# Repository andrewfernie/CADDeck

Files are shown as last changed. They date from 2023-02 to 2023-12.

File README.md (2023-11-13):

# CADDeck
This is the source repository for the software for CADDeck, a combined joystick and touch panel display suitable for use with common CAD programs. 
## Hardware Configuration
### Current "AFUDirk" hardware
It is configured to use the hardware designed by AFUDirk here (https://github.com/AFUDIrk/CADDeck)
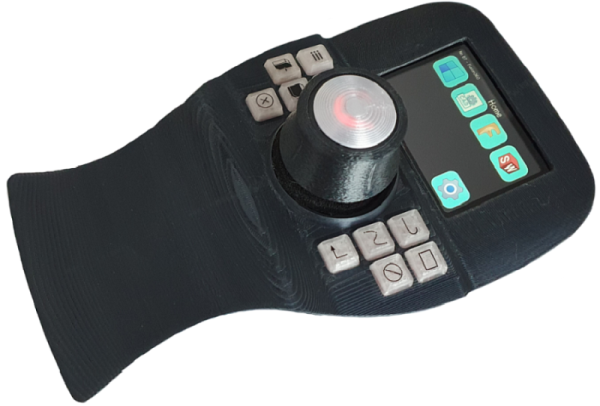
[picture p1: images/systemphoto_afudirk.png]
AFUDirk System Photo

It includes:
1. Two axis joystick (e.g. for X, Y pan)
2. Two axis knob (up/down and rotate left/right) with a capacitive switch for mode select 
3. Ten switches around the base (e.g. measure, ESC...)
5. LCD touch panel with up to 10 screens of 12 buttons

All H/W buttons as well as the touch panel buttons are programmable through a web page.

Basic principles of operation and software build still apply, and are described below, but details may differ so some updates to the text are needed.

### Version 1 (deprecated)
Initial versions of the software were built for this hardware that has a knob with four buttons and a thumbwheel encoder. No work is currently being done on this version of the hardware, but details can be found in the branch Version_1-Four_Buttons.
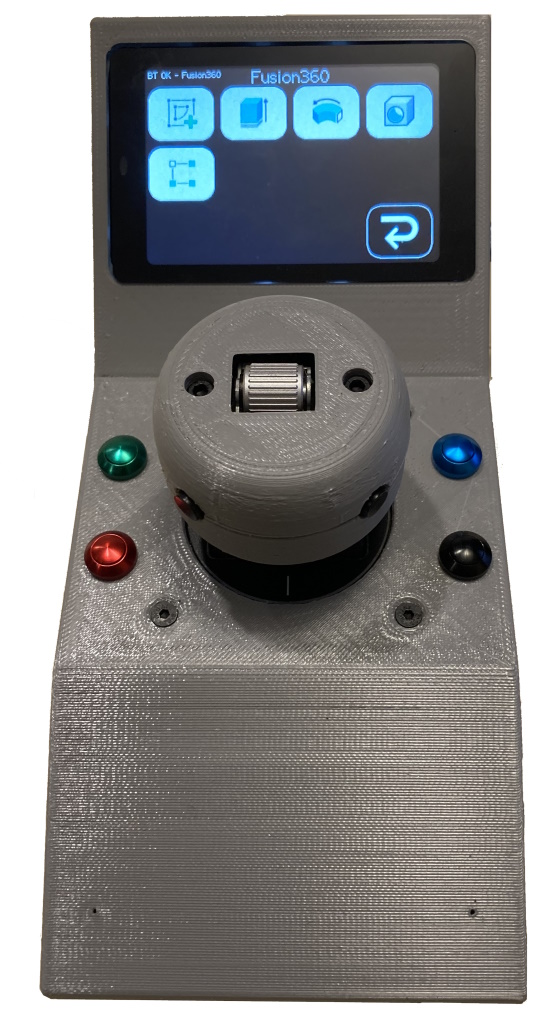
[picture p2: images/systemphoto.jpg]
Original Version 1 System


## PC Interface
It connects to the PC via Bluetooth using the HID interface (i.e. it looks like a keyboard and mouse to the PC). A USB-C port is provided for power and to download code. Location of the USB-C port on the left side is not ideal, but that is where it is on the screen being used. It should be possble to run power to the unit and hardwire it to the screen rather than using the USB-C for power but I have not tried this.

## SpaceMouse Emulation
While the basic mode uses mouse/keyboard combinations for viewpoint control, a SpaceMouse emulation mode is also available. This requires an external Raspberry Pi Pico board running this software (https://github.com/andrewfernie/magellan-spacemouse), as a fork from the project of the same name by "jfedor2". This board is connected to a serial port on the CADDeck WT32-SC01 board, and is also connected to the PC via USB. Further work is required to avoid the need for simultaneous use of Bluetooth and USB interfaces.

## Touch Panel
The touch panel is adapted from Dustin Watt's FreeTouchDeck project (https://github.com/DustinWatts/FreeTouchDeck.git) which I modified to increase the button count, etc.  (https://github.com/andrewfernie/FreeTouchDeckWT32.git). For this project I added support for the joystick, encoder, and buttons.  The easiest way to get it going is to use a WT32-SC01 board (http://www.wireless-tag.com/portfolio/wt32-sc01/). Purchase the basic board, not the "Plus" version as the Plus uses a parallel interface to the LCD panel and doesn't leave enough IO lines free for the joystick and buttons, etc. The board includes an ESP32 module, and a 3.5" LCD with capacitive touchscreen.

## S/W Build Notes:
1. The build uses the PlatformIO IDE for VSCode. Install VSCode, then the PlatformIO plugin and you should be good to go.  
2. You need to make sure that the appropriate pins are defined for your hardware configuration. I built mine for the WT32-SC01 and have built the code for a handwired ESP32 module + resistive touchscreen. 
3. You may see build messages like
        
        In file included from include/CADDeck.h:14,
                 from include/SaveConfig.h:3,
                 from src/SaveConfig.cpp:1:
        .pio/libdeps/esp-wrover-kit/TFT_eSPI/TFT_eSPI.h:909:8: warning: #warning >>>>------>> TOUCH_CS pin not defined, TFT_eSPI touch functions will not be available! [-Wcpp]
        #warning >>>>------>> TOUCH_CS pin not defined, TFT_eSPI touch functions will not be available!`
    
    You can get rid of these by defining TOUCH_CS in platformio.ini to any unused pin that is a valid output pin. The alternative is to not define TOUCH_CS (delete the line, or put a semi-colon in front of it) and just ignore the messages.

        #define TOUCH_CS=33

4. The system tries to display the logo in "CADDeck_logo.bmp" at startup. If you don't want anything displayed make sure that the file doesn't exist. In this case you will see a message like the following on the serial port. As long as you didn't weant anything displayed at startup ignore the message.
        
        [  1159][E][vfs_api.cpp:104] open(): /littlefs/logos/CADDeck_logo.bmp does not exist, no permits for creation

5. You may  see some error messages like 
   
        [vfs_api.cpp:104] open(): /littlefs/list does not exist 
        
   This is a known issue with ESPAsyncWebsServer related to LittleFS supporting folders while SPIFFS does not. See https://github.com/lorol/

6. Having trouble? There are some debug messages that can be enabled in FreeTouchDeck.h
   
        #define LOG_MSG_BASIC 1
        #define LOG_MSG_LEVEL 1  // 1=ERROR, 2=ERROR+WARN, 3=ERROR+WARN+INFO
        #define LOG_MSG_DEBUG 0
        #define LOG_MSG_TOUCH_DEBUG 0  // messages to console each time a touch is detected

   Try setting LOG_MSG_LEVEL to 3 and you will get quite a few more status messages

# Setup
Once the unit is assembled and the display is coming up you should see the main page.
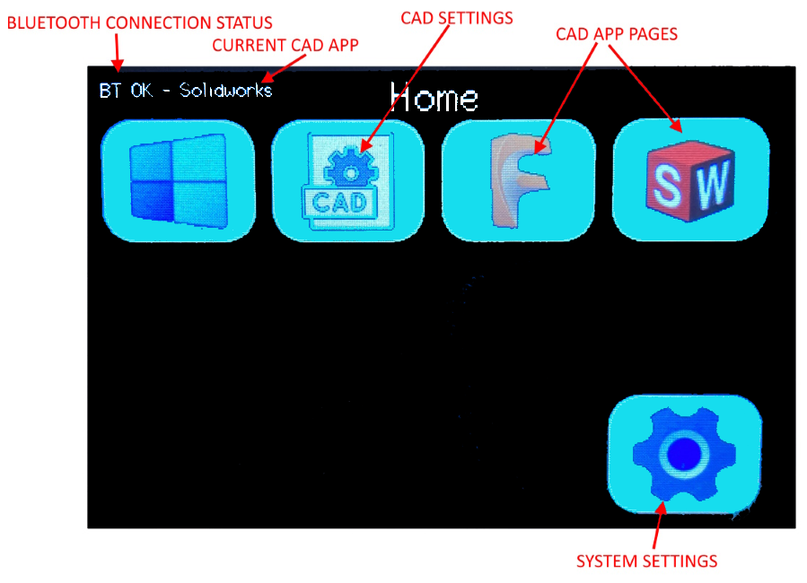
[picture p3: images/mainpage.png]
Main Page


Go to the CAD Settings page.
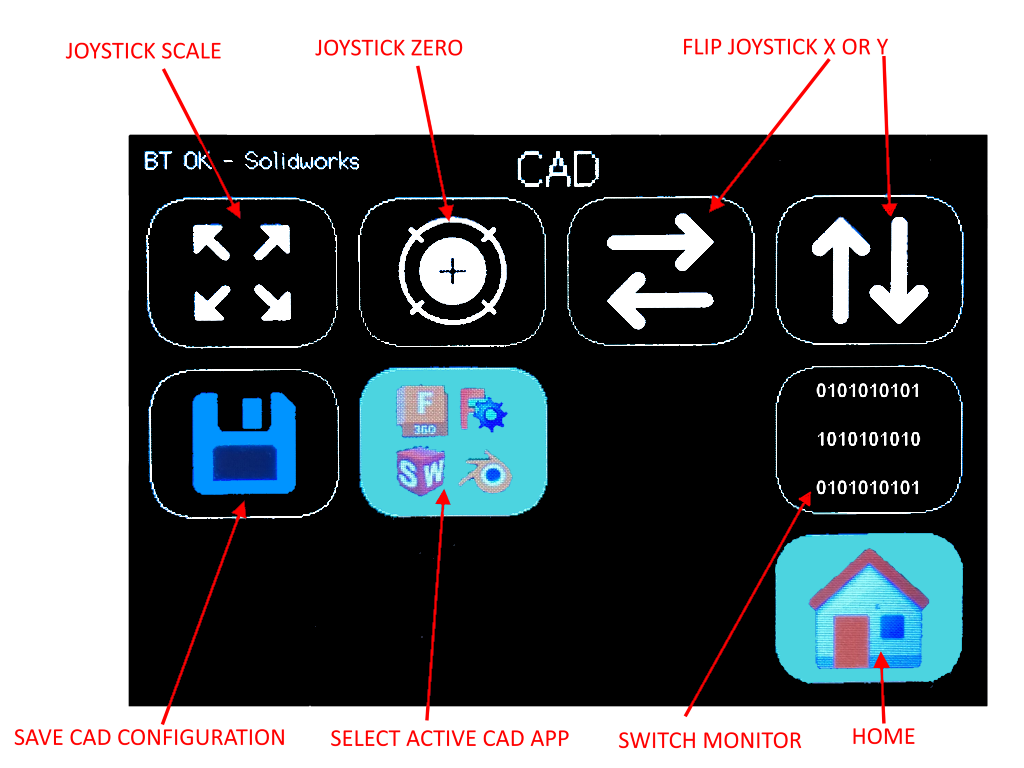
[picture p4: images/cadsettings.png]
CAD Settings Page


Then the Switch Monitor page.

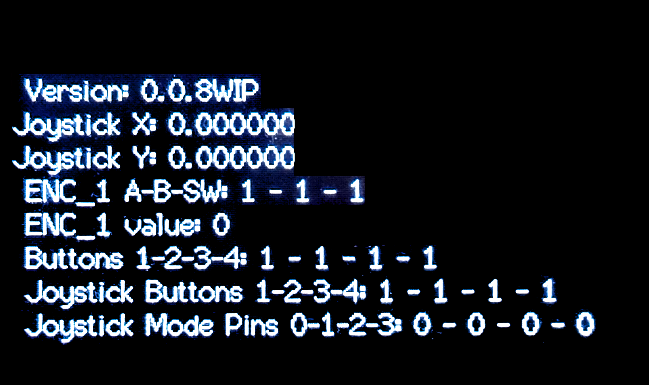
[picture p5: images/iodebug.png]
Switch Monitor Page


It displays the status of the joystick, encoder, and buttons. You should be able to see the result of each joystick movement or button selection. Note that the values are shown as 1 when not selected and 0 when selected (pushed).

The joystick X and Y data may be bouncing around a bit. This is normal as the joystick is not calibrated at this point. To calibrate the joystick:
1. Go back to the CAD Settings page
2. Press the Joystick Zero button when the joystick is centered and still. This sets the zero point for the joystick. 
3. Press the Joystick Scale button and move the joystick around to the extremes in X and Y. You have 5s. Once the function finishes the calibration parameters will be calculated and the joystick should show a range of roughly +/- 1 in both X and Y. 
4. If you are happy with the calibration, press the Save CAD Configuration button and the parameters will be saved to the cadparams.json file in the ESP32. This file can be downloaded from the ESP32 to your PC via the CAD Settings page in the configurator. It is a good idea to do this and to copy the file to the data\config folder in the CADDeck code so that you won't lose the parameters next time you upload the data folder to the ESP32.
4.  If you are not happy with the results, try again.

Bind your computer to the CADDeck using the Bluetooth setings page on your computer.

# Configuration
Note that all of the pages shown or mentioned above are samples. Every page can be reorganized and customized to suit your needs via the configurator.

## WiFi Configuration
The configurator is accessed via a web browser on a computer or tablet connected to the same network as the ESP32. To enable the configurator go to the settings page on the touch panel and select the WiFi Enable button.  
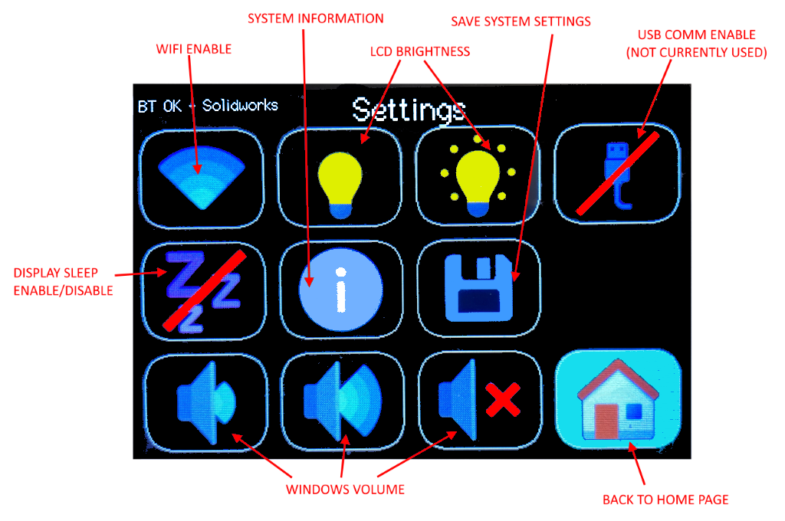
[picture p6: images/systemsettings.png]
System Settings


If you have already configured your wifi connection in wificonfig.json you should see a message saying that it has connected to the wifi and will display the IP address. At that point you can go to your browser and enter the IP address top connect. The configurator will be displayed.
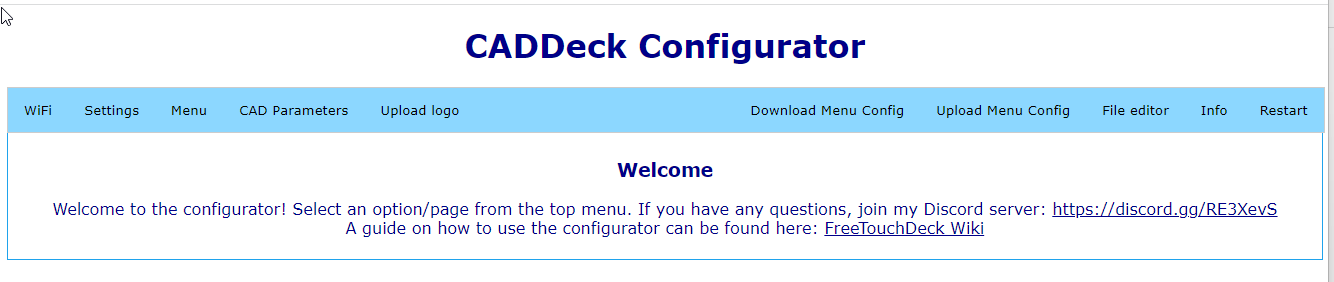
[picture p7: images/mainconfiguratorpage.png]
Configurator Main Page


If you have not already configured the wifi you should see a message saying that an access point (AP) has been created with a network name and IP address. You will need to connect your computer to the network provided, and then point your browser at the IP address. Once the configurator screen is displayed in your browser go to the wifi page and enter your network SSID and password. Then select "Save WiFi Config" to save the settings. 

## Menu Configuration
The main change from the original FreeTouchDeck is to allow more buttons per page  - the screen area is just a bit smaller than the size of twelve StreamDeck buttons which seems reasonable. The code is currently set to three rows of four buttons, but can be changed to three rows of five buttons (or two rows of four, etc.) by modifying CADDeck.h: "#define BUTTON_ROWS 3" and "#define BUTTON_COLS 5".  In principle it should support larger arrays, but not tested, and the configurator page is set to a maximum of 3x5. 

The configurator displays an array of three rows of five buttons, with a drop down list to select the menu page to be modified. If you are using fewer than 3x5, simply ignore the extra rows and columns. On the to-do list is to generate the HTML dynamically to correspond with the number of rows and columns.
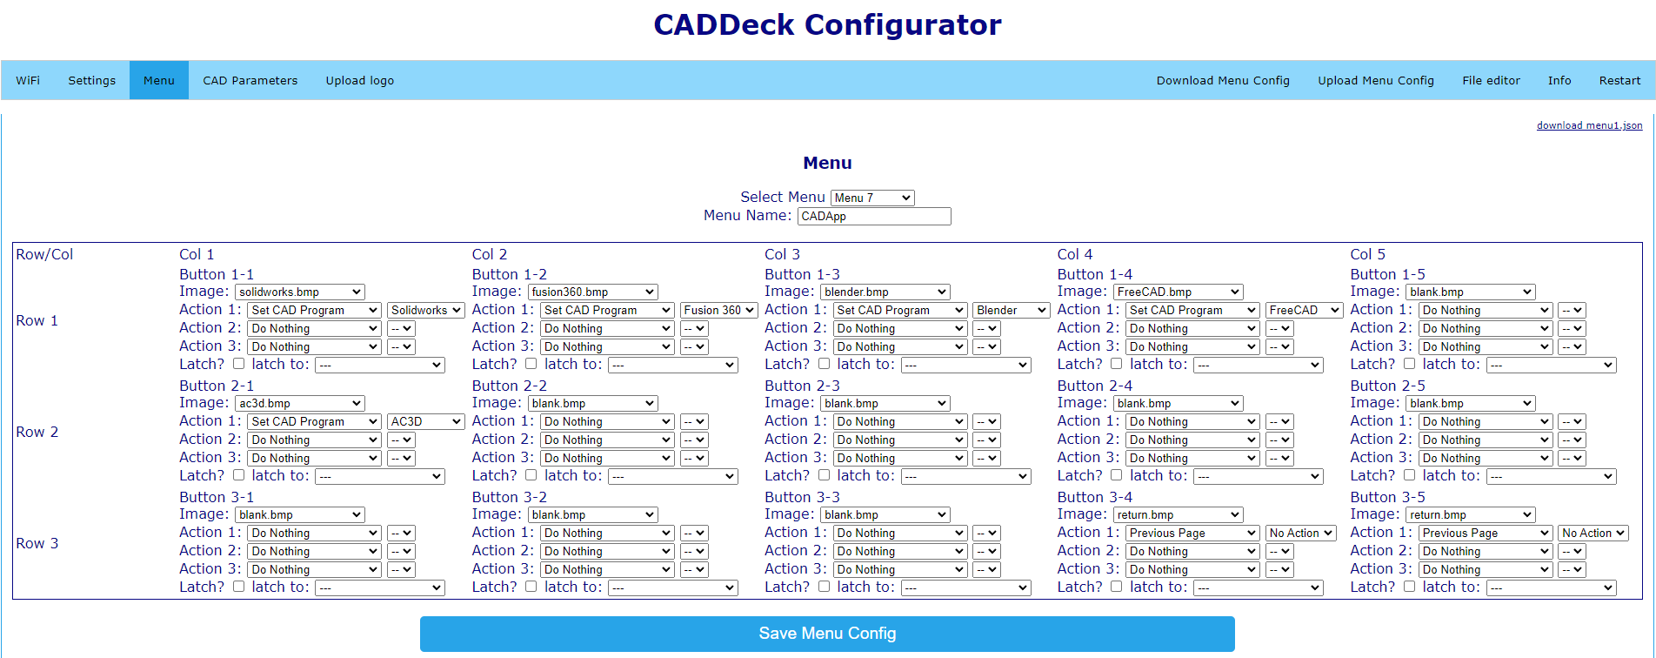
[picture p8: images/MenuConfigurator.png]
Menu Configurator


Each Menu page has a 2D array of programmable buttons, and each button has an array of 3 actions that can be defined for when the button is pressed.

You can set different background colors for a button that performs an action (black background in the image above), or links to another menu (light blue in the image.) This is controlled on the Settings page of the configurator.

If you don't want to use all buttons use the configurator to set the logo to "blank.bmp" and make sure that there are no actions defined for that button. Any button with those characteristics will not be drawn.

One limitation is the size of the FLASH used for the configuration files and icons displayed on the touch screen. The icons are 75x75 24-bit color BMP files, each one taking about 17kB.  If you run out of space your only option is to check to see if any are unused and delete them.

## Hardware Buttons
Configuration of the hardware buttons is via a dedicated page within the same web-based configurator as for the LCD panel. 
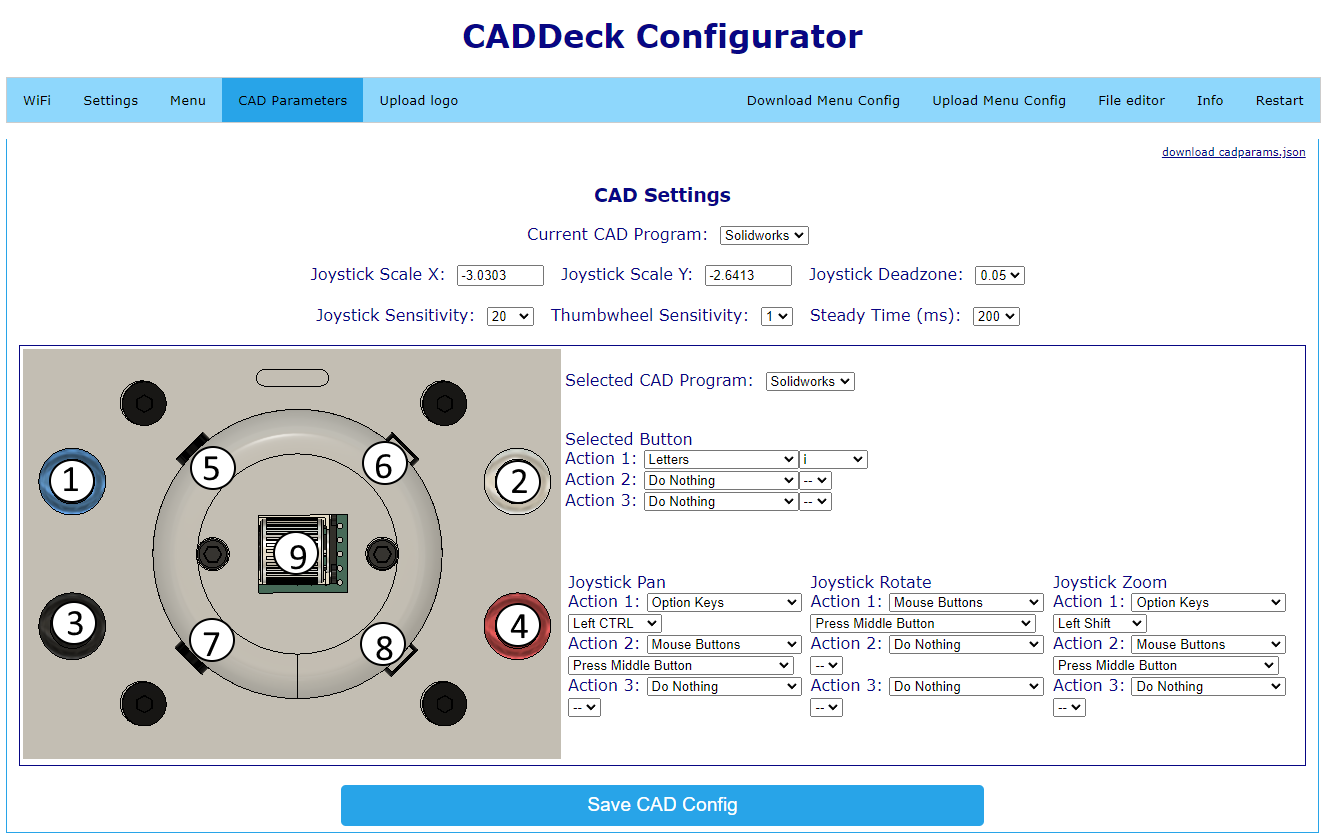
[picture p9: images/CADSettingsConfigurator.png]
CAD Settings Configurator


The top section includes:
1. Current CAD program: This is the program whose settings will be loaded when the CADDeck is restarted
2. X and Y scaling parameters for the joystick. These can be set manually, but a function is provided to capture data as the joystick is moved to its extremes and calculate the scalings for you. The output scaling is +/-1
3. Joystick deadzone. Any X or Y value with an absolute value below this number is set to zero.
4. Joystick sensitivity. Joystick values are multiplied by this as they are converted to mouse movement commands
5. Thumbwheel sensitivity. The encoder value is multiplied by this as it is converted to mouse movement commands

Below that is the button action definition. The same approach to defining the actions is used as for the LCD panel buttons. The actions are:
1. Selected CAD program. The program whose settings are being modifed in that part of the configurator. Separate definitions of these settings are kept for each of the five CAD programs available.
2. Selected Button. One of the nine buttons shown in the image to the left. Click  one of the indicated areas in the image then modify the actions for that button as needed.
3. The actions that must be taken to enable pan/rotate/zoom to be controlled by the joystick (i.e. the mouse) within the selected CAD program. Note that the definition of what is needed to control pan/rotate/zoom is separate from which button enables that mode. As an example, Solidworks needs the middle mouse button to be held down to rotate the view. So, JoystickRotate/Action1 is set to "Mouse Buttons" and Value1 is set to "Press Middle Button". To assign the Rotate function to button 8, click "8" in the image to the left, then set SelectedButton/Action1 to "CAD Functions" and Value1 to "Joystick Rotate"
Configuring the Rotate function
At the very bottom is the "Save CAD Config" button. When selected the settings for all CAD programs are saved on the ESP32 in file cadparams.json

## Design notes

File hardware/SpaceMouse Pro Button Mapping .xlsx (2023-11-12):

Button Mapping
CAD Deck Button | Button Bit Sent To 3DConnexion driver | SpaceMouse Pro Button
0 | 12
1 | 13 | 1
2 | 14 | 2
3 | 15 | 3
4 | 22 | 4
5 | 25 | ESC
6 | 23 | CTRL
7 | 24 | ALT
8 | 0 | SHIFT
9 | 1 | MENU
10 | 2 | FIT
11 | 4 | T
12 | 5 | R
13 | 8 | F
14 | 26 | Square with Arrow (Rotate View)
15 | 3 | Lock
16 | 6 | Not available
17 | 7 | Not available
18 | 9 | Not available

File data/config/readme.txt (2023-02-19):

Before downloading the file system to the board rename the file:
	wificonfig.json.default
	
to
	wificonfig.json

and edit the ssid and password fields to your wifi network name and password.

You can always set these through the configurator when the wifi is running as an AP, 
but then you will have to repeat that process every time you download the file system again.

wificonfig.json is listed in the .gitignore file so that it doesn't get uploaded to a public 
repository by mistake and expose your wifi credentials.

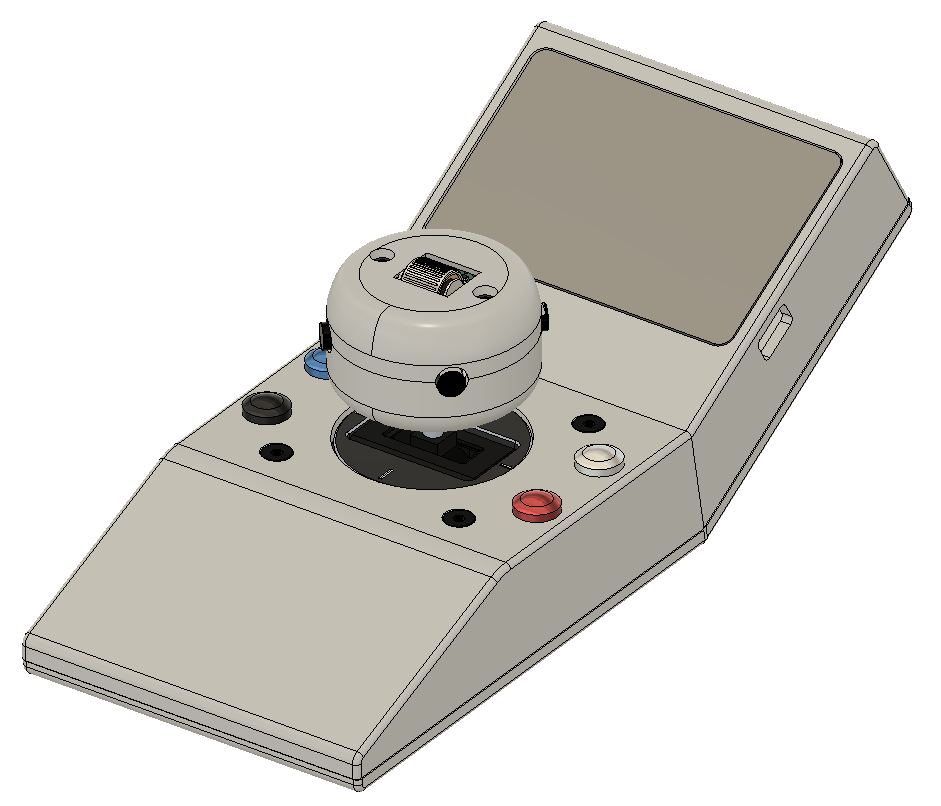
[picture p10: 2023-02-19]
hardware/ExteriorView1.png

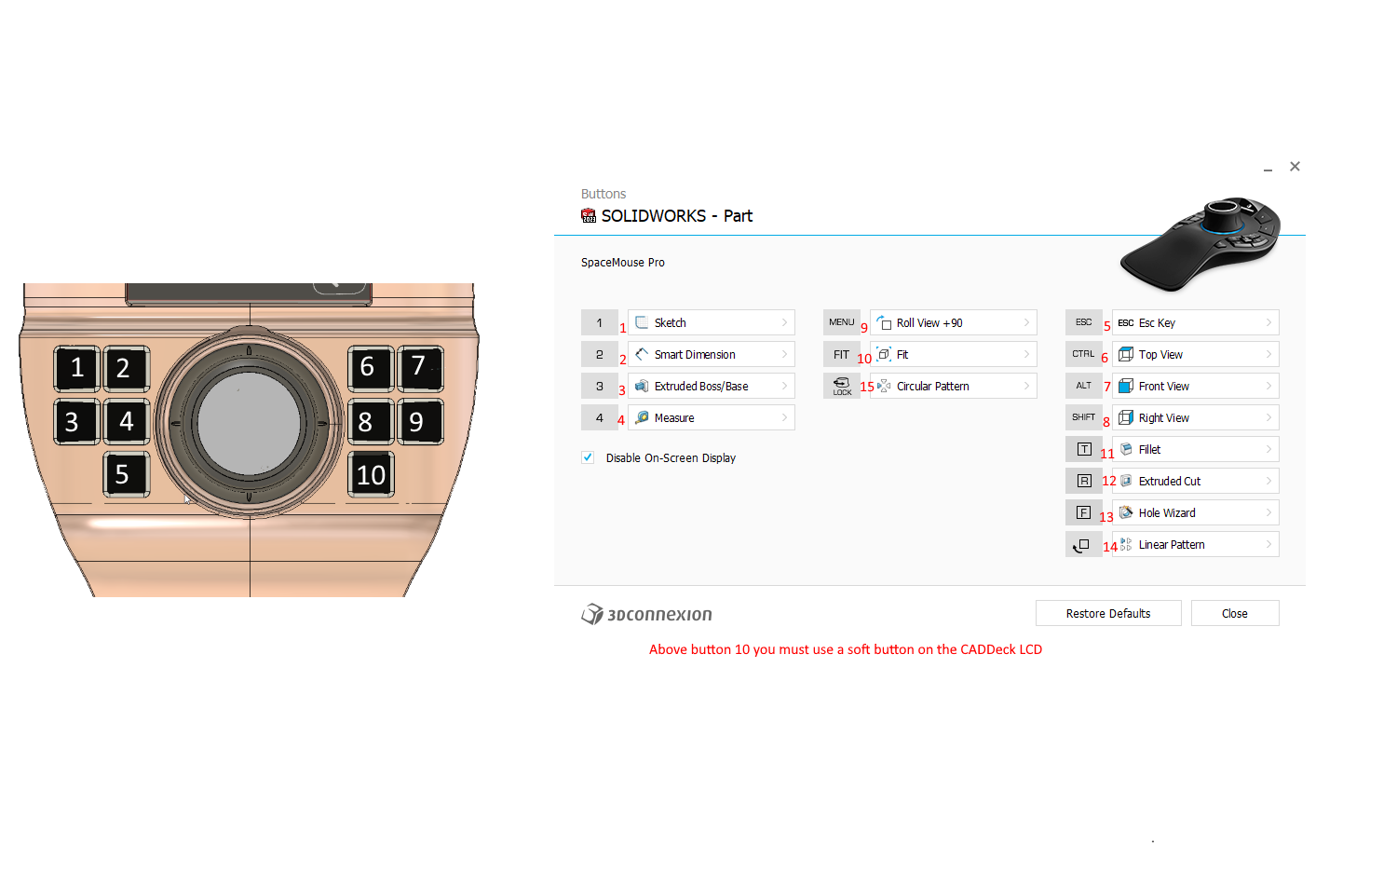
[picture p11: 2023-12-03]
images/SpaceMouseButtonMapping.png

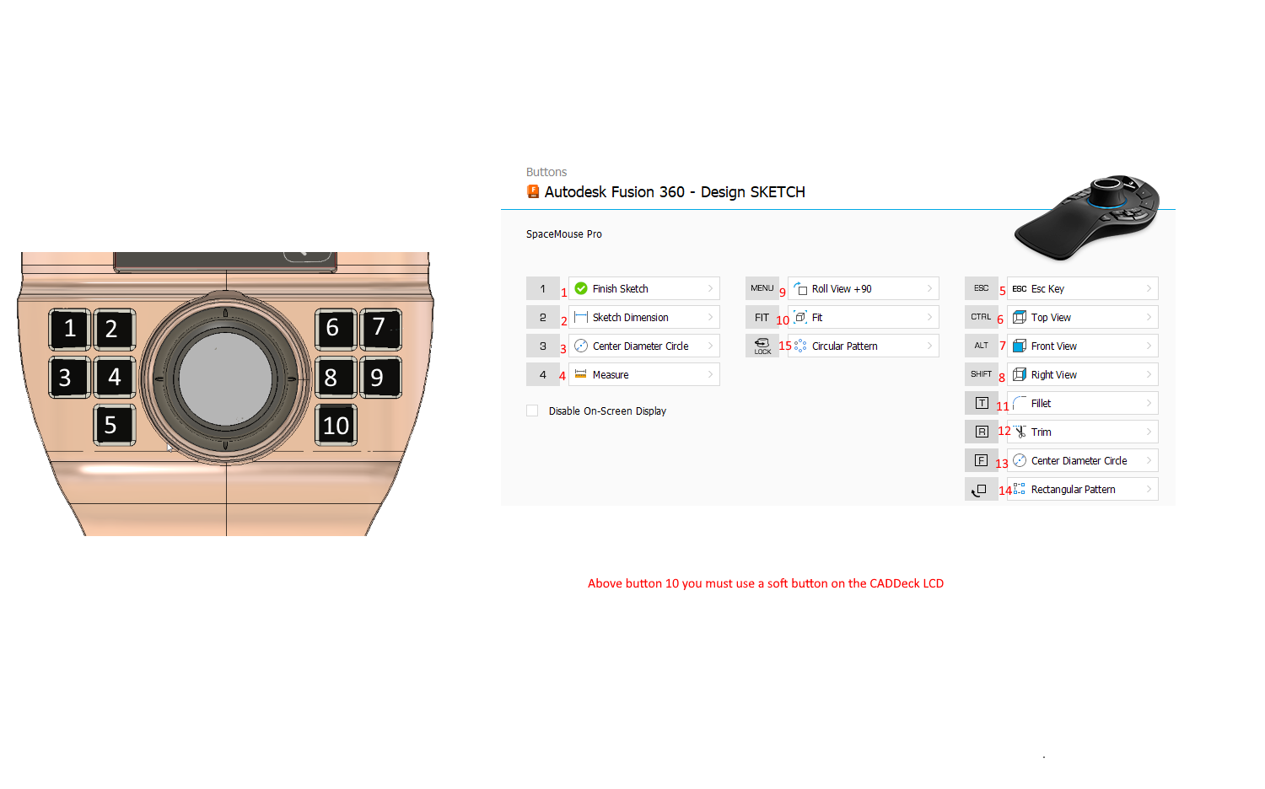
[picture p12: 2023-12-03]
images/SpaceMouseButtonMapping-F360Sketch.png

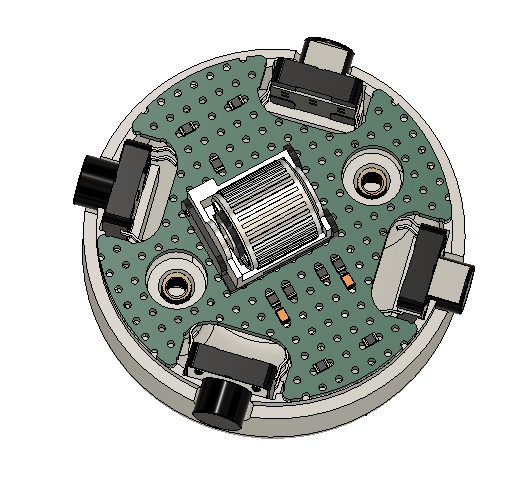
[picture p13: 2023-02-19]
images/KnobInterior.png

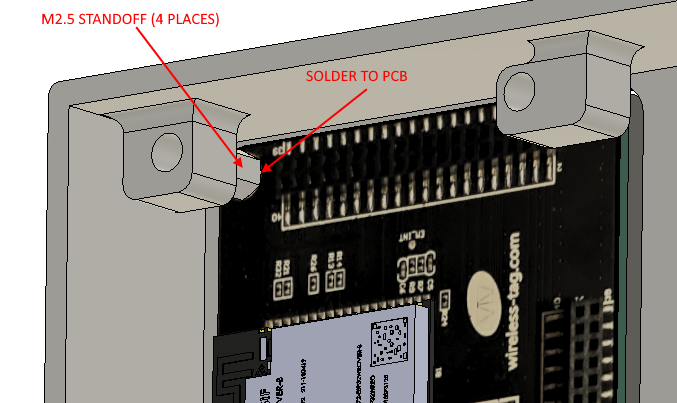
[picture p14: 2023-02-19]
images/ScreenAttachment.png

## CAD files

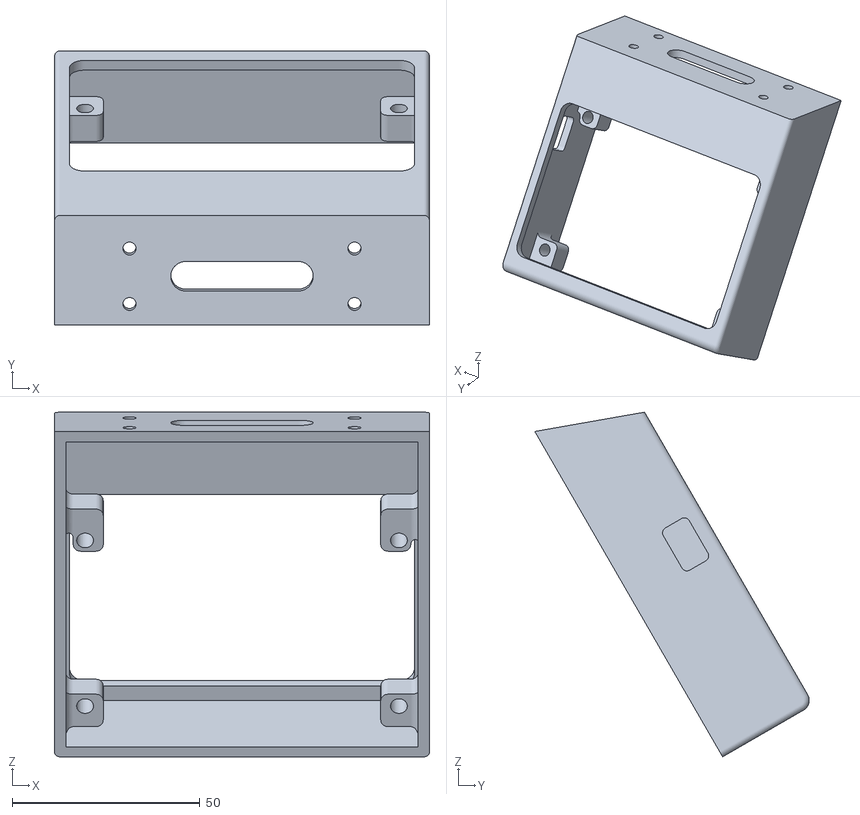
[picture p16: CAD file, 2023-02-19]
hardware/Case/Case Top Rear.stl
100.0 x 73.2 x 91.9

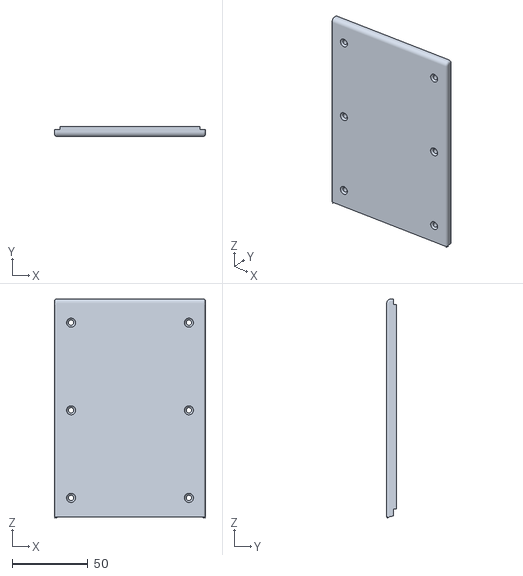
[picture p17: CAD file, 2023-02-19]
hardware/Case/Case Bottom Front.stl
100.0 x 6.50 x 145.0

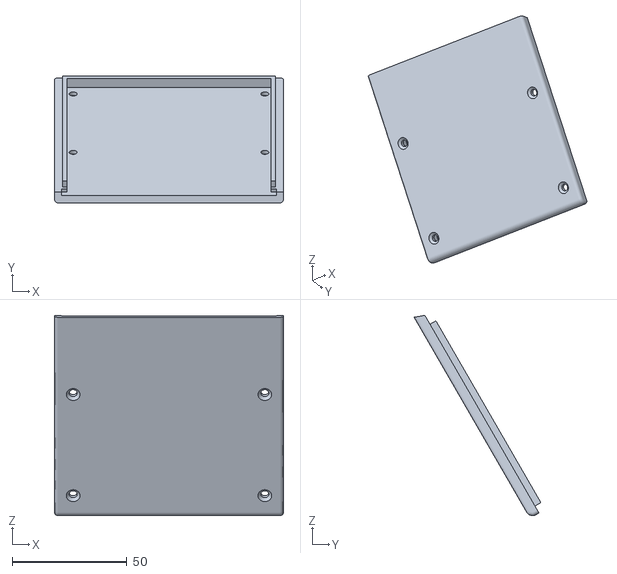
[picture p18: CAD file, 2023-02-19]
hardware/Case/Case Bottom Rear.stl
100.0 x 55.4 x 87.5

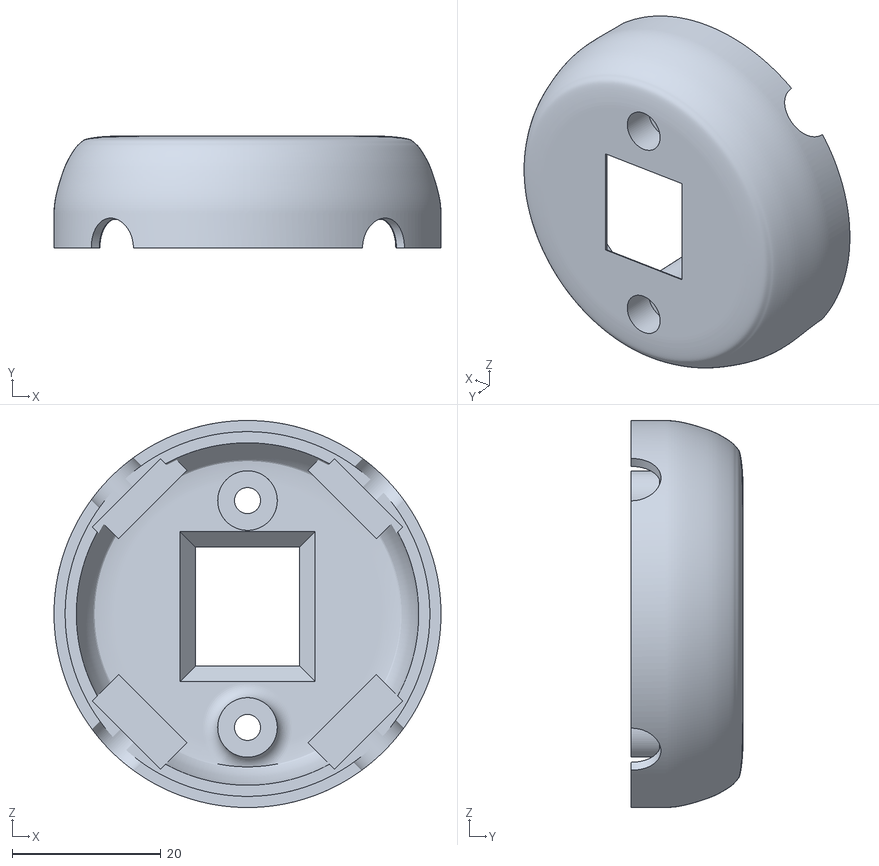
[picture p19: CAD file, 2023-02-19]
hardware/Case/Knob Top.stl
52.0 x 15.0 x 52.0

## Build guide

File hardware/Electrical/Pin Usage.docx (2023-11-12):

Pin Usage

December 10, 2022

11:00 AM

GPIO | Input | Output | Function | ADC | DAC | RTC | Capacitive Touch | WT32-SC01 | CADDeck Std | CADDeck 10 Buttons | Notes
0 | pulled up | OK | | ADC2_CH1 | | RTC_GPI011 | T1 | I2S_MCLK (Available) | | | outputs PWM signal at boot, must be LOW to enter flashing mode
1 | TX pin | OK | | | | | | | | | debug output at boot
2 | OK | OK | | ADC2_CH2 | | RTC_GPI012 | T2 | Available | | | connected to on-board LED, must be left floating or LOW to enter flashing mode
3 | OK | RX pin | | | | | | | | | HIGH at boot
4 | OK | OK | | ADC2_CH0 | | RTC_GPI010 | T0
5 | OK | OK | | | | | | I2S_SCLK (Available) | | | outputs PWM signal at boot, strapping pin. I2S is a digital audio interface.
6 | x | x | (SCK/CLK) | | | | | | | | connected to the integrated SPI flash
7 | x | x | (SDO/SD0) | | | | | | | | connected to the integrated SPI flash
8 | x | x | (SDI/SD1) | | | | | | | | connected to the integrated SPI flash
9 | x | x | (SHD/SD2) | | | | | | | | connected to the integrated SPI flash
10 | x | x | (SWP/SD3) | | | | | | | | connected to the integrated SPI flash
11 | x | x | (CSC/CMD) | | | | | | | | connected to the integrated SPI flash
12 | OK | OK | | ADC2_CH5 | | RTC_GPI015 | T5 | (TFT_MISO) | | | boot fails if pulled high, strapping pin
13 | OK | OK | | ADC2_CH4 | | RTC_GPI014 | T4 | LCD_SDA (TFT_MOSI)
14 | OK | OK | | ADC2_CH6 | | RTC_GPI016 | T6 | Output LCD_SCL (TFT_SCLK) | | | outputs PWM signal at boot
15 | OK | OK | | ADC2_CH3 | | RTC_GPI013 | T3 | TFT_CS | | | outputs PWM signal at boot, strapping pin
16 | OK | OK | | | | | | Not available on WROVER-B
17 | OK | OK | | | | | | Not available on WROVER-B
18 | OK | OK | | | | | | I2C_SDA (TP,EM20918) | Also PC8575 SDA | Also PC8575 SDA | Pulled to 3.3V through 10k
19 | OK | OK | | | | | | I2C_SCL (TP,EM20918) | Also PC8575 SCL | Also PC8575 SCL | Pulled to 3.3V through 10k
21 | OK | OK | | | | | | Output LCD_RS
22 | OK | OK | | | | | | Input LCD_REST
23 | OK | OK | | | | | | Output - LCD_LED (Display brightness)
25 | OK | OK | | ADC2_CH8 | DAC1 | RTC_GPI06 | | I2S_LRCK (Available) | ENC_1_A | | I2S is a digital audio interface.
26 | OK | OK | | ADC2_CH9 | DAC2 | RTC_GPI07 | | I2S_DSDIN (Available) | ENC_1_B | | I2S is a digital audio interface.
27 | OK | OK | | ADC2_CH7 | | RTC_GPI017 | T7 | Available | PCF8575 INT | PCF8575 INT
32 | OK | OK | | ADC1_CH4 | | RTC_GPI09 | T9 | Available | Roll (X) | Roll (X)
33 | OK | OK | | ADC1_CH5 | | RTC_GPI08 | T8 | Available | Pitch (Y) | Pitch (Y)
34 | OK | NO | | ADC1_CH6 | | RTC_GPI04 | | Available | ENC_2_A (future) | Zoom (analog) | No pullup resistor available
35 | OK | NO | | ADC1_CH7 | | RTC_GPI05 | | I2S_ASDOUT (Available) | ENC_2_B (future) | Rotate (Analog) | No pullup resistor available
36 | OK | NO | | ADC1_CH0 | | RTC_GPI00 | | SENSOR_VP, EM20918 EM_INT | | | No pullup resistor available
37 | | | | ADC1_CH1 | | | | Not available | | | Not Available on WROVER-B
38 | | | | ADC1_CH2 | | | | Not available | | | Not available on WROVER-B
39 | OK | NO | | ADC1_CH3 | | RTC_GPI03 | | Touch Interrupt, SENSOR_VN | | | No pullup resistor available

PCF8575 Pinout (10 Buttons)

Pin | Function | | Pin | Function
P0 | BUTTON_9 | | P8 | BUTTON_1
P1 | BUTTON_10 | | P9 | BUTTON_2
P2 | | | P10 | BUTTON_3
P3 | | | P11 | BUTTON_4
P4 | | | P12 | BUTTON_5
P5 | | | P13 | BUTTON_6
P6 | | | P14 | BUTTON_7
P7 | | | P15 | BUTTON_8

Move to bits 0-7, and/or use a PCF8574 in any future version

PCF8575 Pinout (Std)

Pin | Function | | Pin | Function
P0 | | | P8 | BUTTON_1
P1 | | | P9 | BUTTON_2
P2 | | | P10 | BUTTON_3
P3 | | | P11 | BUTTON_4
P4 | | | P12 | BUTTON_JOY_1
P5 | | | P13 | BUTTON_JOY_2
P6 | | | P14 | ENC_1_SW
P7 | | | P15 | ENC_2_SW

Move to bits 0-7, and/or use a PCF8574 in any future version

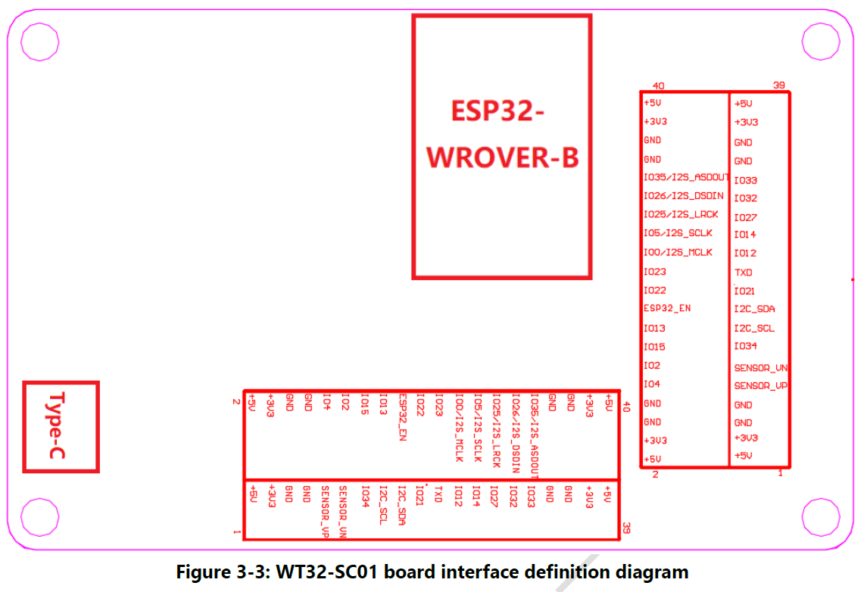
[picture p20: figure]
ESP32- WROVER-B o o o o o o o o o o 0 z +3U3 GND GND 1035/12s_asoou 1026/12S_OSDIN 105„12S SCI-K 100/12S_MCLK 1023 1022 ESP32_EN 1013 1015 104 GND GND 3143 39 *303 GNO GNO 1033 1032 1027 1014 1012 1021 12C_SDA 12C_SCL 1034 SENSOA_U SENSOR U GNO *303 Figure 3-3: WT32-SC01 board interface definition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
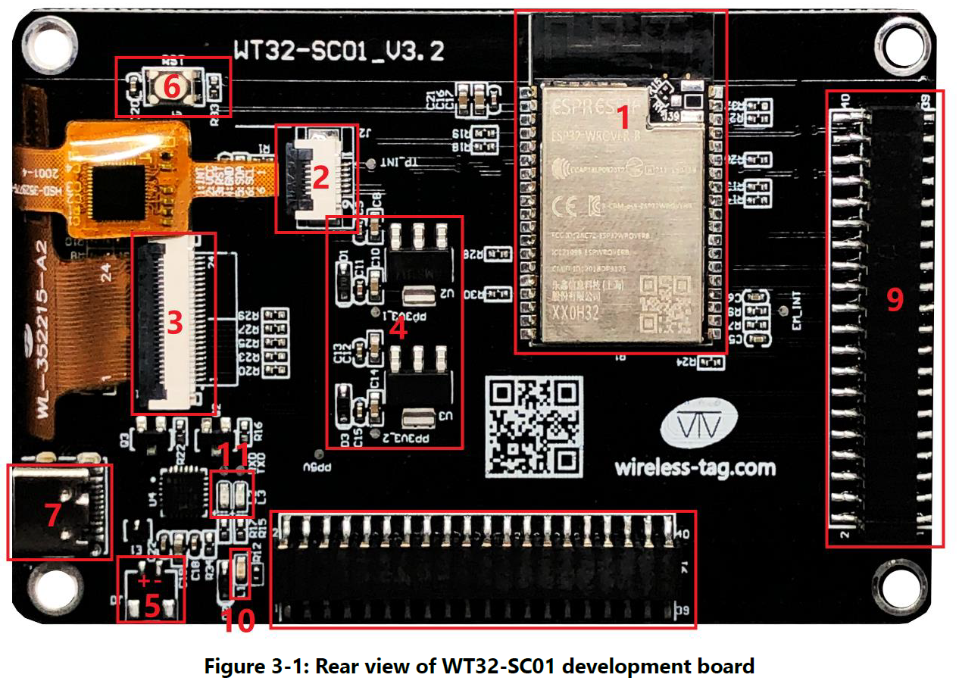
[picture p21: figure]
。 〒 い は ⅱ は な ⅱ い 20q 【 ODS ・ ZE ト M 」 0 」 2 ・ :L-E n6 こ Z ・ つ ー 日 OS ー Z の ト ユ

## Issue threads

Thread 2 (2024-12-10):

Esp32 will not connect to wifi

feaver12, 2024-12-10:
I have followed the instructions as closely as i can,but am having a problem with littleFS. I have edited wificonfig.json and added my credentials, but the file is not being uploaded to the esp32. As well as the CADDeck_logo.bmp. i get the following error in the serial monitor, and cannot see the CADDeck on my WIFI network. BT seems to be working.... Any ideas?
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

[  1893][E][vfs_api.cpp:104] open(): /littlefs/config/wificonfig.json does not exist, no permits for creation
[WARNING]: Config file not found!
[WARNING]: Failed to load WiFi Credentials!
[  1914][E][vfs_api.cpp:104] open(): /littlefs/logos/CADDeck_logo.bmp does not exist, no permits for creation

andrewfernie, 2024-12-11:
Which hardware configuration are you using? Is it the "Current "AFUDirk" hardware" version  shown in the photo at the welcome page for this repository? And are you using the "main" branch?
1. The touch interrupt is used only to wake CADDeck from sleep mode when you touch the screen. It is not used for the general touch panel status to know which button has been pressed. The touch panel status is polled in loop() and if any data is found it is processed.
2. Lets separate the web configurator issue from the normal operation controlling F360.  Does it work properly then, or is it laggy in normal operation? Is the "Guru Meditation Error" connected with the web configurator, or does it happen in normal operation also?
3. As for web configurator...  The more data I added to the web screens the slower and less reliable it seemed to get. Most of the time I ended up editing the json files manually on my PC then uploading the updated files with the PlatformIO "Upload Filesystem Image" command in  VSCode. I wish I could figure out how to get this working but have not been successful. I know that editing codes in json files in a text editor is a pain so have worked on a PC app "CADDeckConfigurator" (https://github.com/andrewfernie/CADDeckConfigurator). It still requires the json files to be uploaded in VSCode, but at least all of the editing is done with a reasonable GUI.  One hassle at the moment is that it is configured for my CADDeck version that adds a small round LCD to the top of the knob. If you don't have that then I can try making the configurator adapt to the earlier version of CADDeck.

feaver12, 2024-12-12:
Yes i was using the main branch in the mentioned repository, but i did notice the "knob" branch was still marked as active with the most recent updates, so i tried that and there was no difference.  Im not too worried about the webserver, as the commands from the touch screen seem to work so far, and i dont mind editing the files manually... just a little confused on what values to input in the json files to call specific keystrokes/shortcut keys.... i will have a look at the configurator tonight.

As far as the guru mediation error and laggy ui goes - yes it is occurring during normal operation/idle. The esp will obviously reboot when this occurs which is a slightly annoying problem because of the boot time etc.
There is one big thing to note though - i have not connected any buttons or joystick etc to the wt32-sc01 yet, as i am waiting for the buttons and rest of the parts needed to arrive from china - and am about to order pcb from jlcpcb later today... so im guessing that could be the main cause of the mediation error...... i will also order one of those small touchscreen for the knob - thats a really cool add on!.
question - the gerber files in this repository are up to date? Or are there some more recent files somewhere?

One more question related to the task handling of the UI -

Is there any reason in particular that you are not using interrupts for the tft? The lack of response from the tft is a little offputting,  its usable, but i feel like it can be much better - having to hold the button until the loop comes back around to that section of the program is a little slow... i have made a few small programs before that utilize interrupts for this very reason, but nothing that has anywhere near as much happening as there is in this project..... if you like i could send you the code i used as a reference.... up to u....

By the way -

Have you thought about swapping the ui handling over to LVGL? The library has "built in" task handlers which make all of this sort of thing a breeze to implement... if not, im sure it would not be too hard to move the logic out of the loop and use an interrupt instead? I could have a look through some of my old projects later, and see if i can try to implement something to make the ui more responsive maybe.... its a little bit daunting because of the size/layout of this project is a bit different to what i have done in the past but i can try lol. Unless there are specific reasons why you have this part of the code operating in the loop? Or not using LVGL?

Anyway - i really like the project! Keep up the good work! I cant wait until the stuff i have ordered turns up so i can try and get this completed

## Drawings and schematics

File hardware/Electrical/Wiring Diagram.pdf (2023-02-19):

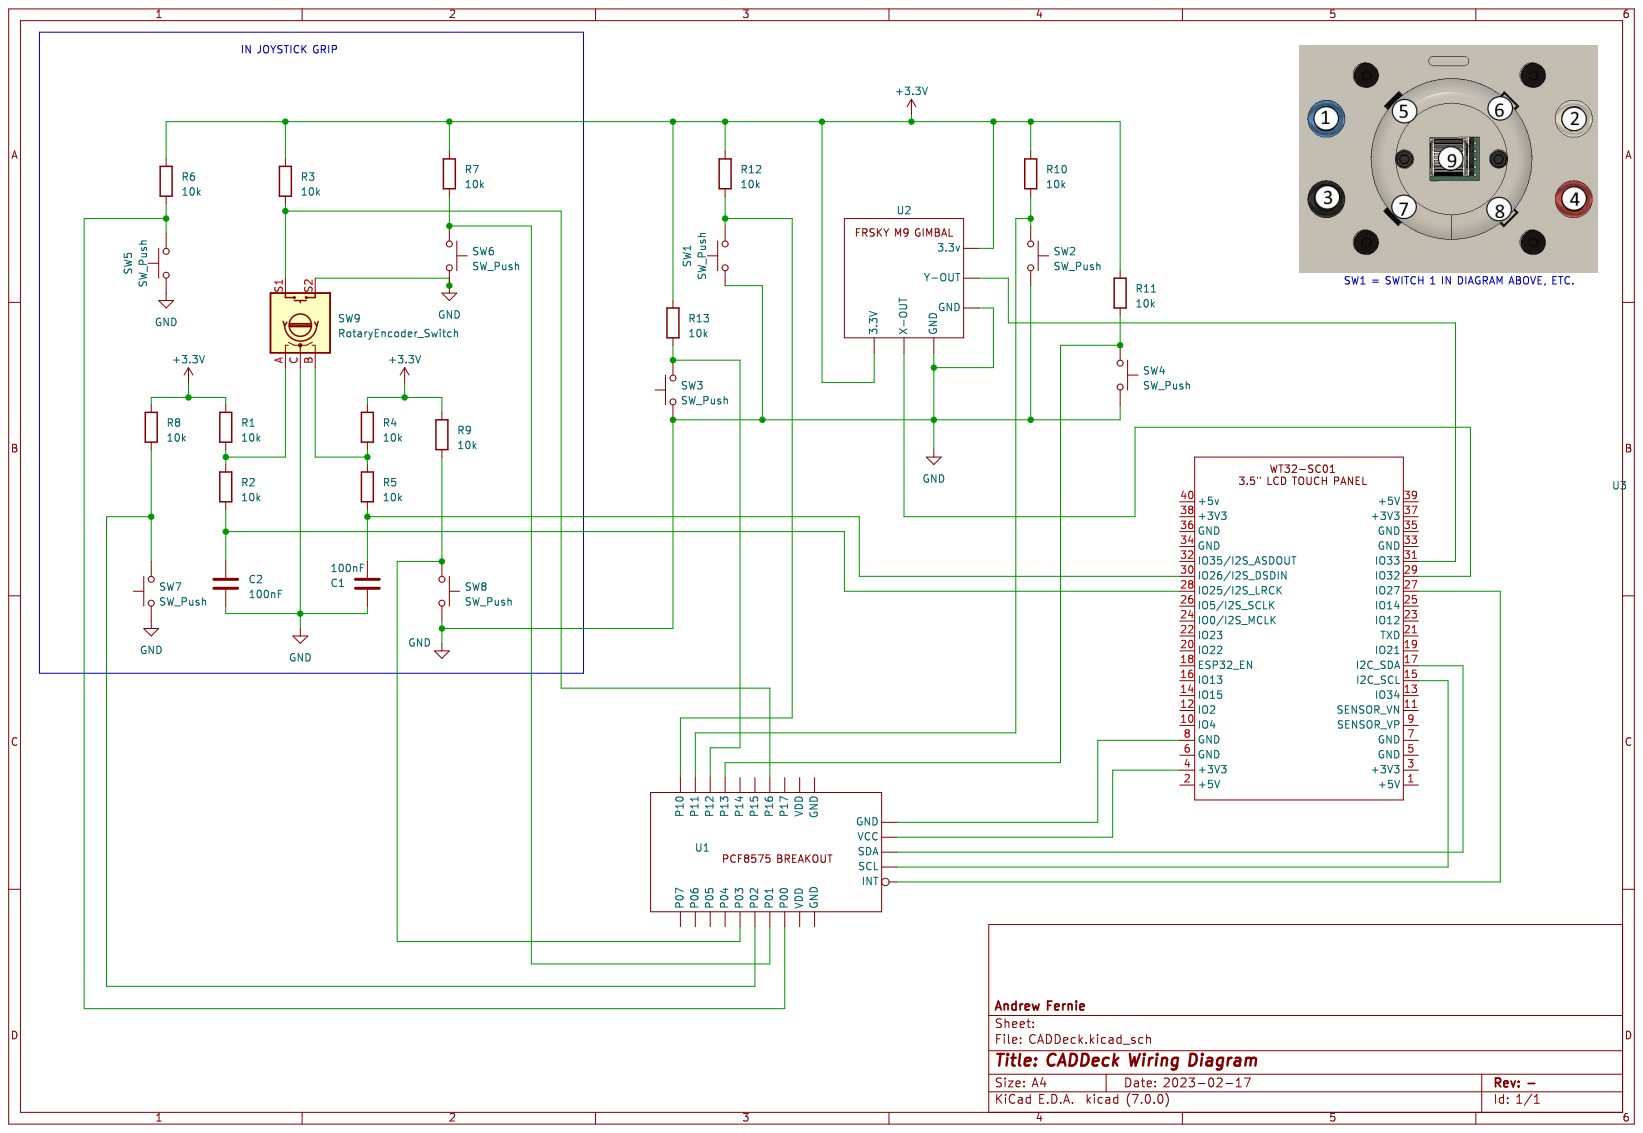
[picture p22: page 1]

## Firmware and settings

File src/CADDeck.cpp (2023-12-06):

/*                                          CADDeck

    Author: Andrew Fernie
    Date: 2023-05-20

    CADDeck is a combined joystick and touch panel display suitable for use with common CAD programs. It includes:

        1. Two axis joystick (e.g. for X, Y pan)
        2. Thumbwheel encoder in the joystick grip (e.g. for zoom) with push switch (e.g. for select)
        3. Four switches around joystick grip (e.g. hold one down while moving joystick for pan and another for rotate)
        4. Four switches around the base (e.g. measure, ESC...)
        5. LCD touch panel with up to 10 screens of 12 buttons

    All H/W buttons as well as the touch panel buttons are programmable through a web page.

    It connects to the PC via Bluetooth using the HID interface (i.e. it looks like a keyboard and mouse to the PC).
    A USB-C port is provided for power and to download code.

    This project is derived from TouchDeck by Dustin Watts. The original TouchDeck project is available at:
    https://github.com/DustinWatts/FreeTouchDeck
r
*/

/*
  Author: Dustin Watts
  Date: 27-08-2020

  My thanks goes out to Brian Lough, Colin Hickey, and the people on my Discord server
  for helping me a lot with the code and troubleshooting! https://discord.gg/RE3XevS

  FreeTouchDeck is based on the FreeDeck idea by Koriwi. It uses the TFT_eSPI library
  by Bodmer for the display and touch functionality and it uses an ESP32-BLE-Keyboard fork
  with a few modifications. For saving and loading configuration it uses ArduinoJson V6.

  FreeTouchDeck uses some libraries from other sources. These must be installed for
  FreeTouchDeck to compile and run.

  These are those libraries:

      !----------------------------- Library Dependencies --------------------------- !
      - Adafruit-GFX-Library (tested with version 1.10.4), available through Library Manager
      - TFT_eSPI (tested with version 2.4.70), available through Library Manager
      - ESPAsyncWebserver (latest version) download from: https://github.com/me-no-dev/ESPAsyncWebServer
      - AsyncTCP (latest version) download from: https://github.com/me-no-dev/AsyncTCP
      - ArduinoJson (tested with version 6.17.3), available through Library Manager
      ---One difference from the original FreeTouchDeck is that this program needs to send
        - both mouse and keyboard events. For this it uses the ESP32-BLE-Combo library
        - ESP32-BLE-Combo download from: https://github.com/BlynkGO/ESP32-BLE-Combo
        - However, the basic download is missing a number of key codes in BLEComboKeyboard.h.
        - I have added these key codes in the version of the library contained in the "lib"
        - folder of this project. If you want to use the original library, you will need to
        - correct the key codes yourself.


      --- If you use capacitive touch screen you will also need a library for that
      - The WT32-SC01 appears to be a FT6336, but works with both of the following libraries
      - Dustin Watts FT6236 Library (version 1.0.2), https://github.com/DustinWatts/FT6236
      - or the FT6336U library (https://github.com/aselectroworks)
      - You can select which library to use in the CADDeck.h file

  !-- Make sure you have setup your TFT display and ESP setup correctly in platformio.ini

        Select the right screen driver and the board (ESP32 is the only one tested) you are
        using. Also make sure TOUCH_CS is defined correctly. TFT_BL is also needed!

*/
#include "CADDeck.h"

#include <Arduino.h>

const char *versionnumber = "10Button V1.1.5 WIP";

/*

 * Version V1.1.5 WIP
 *                   - Additional values for zoom_deadzone and rotate_deadzone in configurator
 * 
 * Version V1.1.4
 *                   - Use stack properly (push current page number then change it, and pop when returning to previous page)
 *
 * Version V1.1.3
 *                   - Started work on support for multiple H/W buttons held down at the same time
 *                   - Renamed BLE device to "CADDeck"
 *                   - Fixed issues with "return to previous page" stack when not on page 0 at start
 *                   - removed a bunch of MSG_DEBUG statements
 *                   - Added images with my SpaceMouse button assignments for Solidworks and F360, and included
 *                     corresponding 3dxz files that can be imported in the 3dx settings app.
 *
 * Version V1.1.2
 *                   - Fix issues with H/W button description handling (wasn't saving, and possible buffer overflows)
 *                   - Prevent possible buffer overflow in filenames (mainly logos)
 *
 * Version V1.1.1
 *                   - Enable knob push/pull (vertical move) while in rotation mode and knob rotate when in translation mode
 *                   - Add SpaceMouse soft button support to configurator
 *
 * Version V1.1
 *                   - Added code for Spacemouse output to serial port. Needs to be hooked up to a Raspberry Pi Pico running this code
 *                     https://github.com/andrewfernie/magellan-spacemouse
 *
 * Version 1.0.0_10Button
 *                   - Using button numbering scheme as defined by AFUDirk
 *                   - Added controllable GPIO pin for LEDs on 10 button card
 *                   - Some messages (in ConfigHelper.cpp) can be displayed in English or German (compile time option). Does not apply
 *                     to messages on web pages, only those stored directly in the C++ code. Will eventually add the rest of AFUDirk's
 *                     messages, but want to look at how to do this in a more elegant way.
 *                   - Support for "click" and "double click" action for button on top of joystick (button 0).
 *                   - Added enumerations for actions. Makes code more readable, but not tied to the values in the
 *                     configurator and configuration json files, so these must be kept alienged manually.
 *
 * Version 0.0.17.10Button
 *                   - Added controllable GPIO functions
 *
 * Version 0.0.13.10Button
 *                   - Removed unneeded configurator code that was previously used to define which buttons were selecting
 *                     joystick actions
 *
 * Version 0.0.12.10Button
 *                   - Fix initialization of active CAD program for configurator
 *                   - Disable sleep timer to see if this is the cause of losing bluetooth connection
 *                   - To help setup debug, the default behavior of button_1 to button_10 (not including button 0) in
 *                     cadparams.json is to send a letter "a" through "j". This can be changed in the configurator.
 *
 * Version 0.0.11.10Button
 *                   - Zoom control active without pushing button
 *
 * Version 0.0.10.10Button
 *                   - Added hardcoded control functionality for Solidworks, Fusion360, Blender, FreeCAD, and AC3D
 *
 * Version 0.0.9.10Button.WIP
 *                   - More support for 10 buttons, analog zoom control, and analog rotate control. Hardcoded for Fusion360 only.
 *
 * Version 0.0.8.10Button.WIP
 *                   - Added support for 10 buttons, analog zoom control, and analog rotate control
 *
 * Version 0.0.7     - Adapted for four button knob.
 *                   - Added support for AC3D as fifth CAD program
 *
 * Version 0.0.6     - Add top status bar with BT link status and active CAD program
 *
 * Version 0.0.5     - Integrated thumbwheel encoder. The encoder is connected directly to the ESP32 as there were problems with getting the
 *                     interrupts working properly with the encoder functions in the PCF857X library.
 *                   - Using "PCF857X" library for I2C IO expander. This came from the PCF8574 library, but has
 *                     been modified to support the PCF8575. The PCF8575 is a 16-bit IO expander, but the library
 *                     for the PCF8575 was well behind the PCF8574 library functionality. A #define statement in
 *                     the PCF857X library allows the library to be used for both the PCF8574 and PCF8575.
 *                   - Overall, working well. Next steps are:
 *                      - Highlight the selected CAD program
 *                      - Get the web configrator up to date with all the changes made to the code
 *
 *
 * Version 0.0.4     - Allow any menu to be displayed on startup. Previously, the default menu had to be menu0.json
 *                   - h/w button function definitions in cadparams.json
 *                   - CAD program selection in cadparams.json
 *                   - Joystick functionality for pan, rotate, zoom working
 *
 * Version 0.0.3     - Basic joystick functionality for pan, rotate, zoom
 *
 * Version 0.0.2     - Updated to use ESP32-BLE-Combo so that Mouse events can be sent as well as Keyboard events
 *
 * Version 0.0.1     - Starting from FreeTouchDeckWT32 V0.2.1-AF
 *
 * Version 0.2.0-AF  - Merge pull request that improves key spacing calculations by adding a margin around the screen.
 *
 * Version 0.1.12-AF - Use PSRAM to save logos and draw directly from PSRAM to screen. Overall, drawing a 4x3 keypad goes from about 2.2s to about 1.1s
 *                     the first time the menu is accessed down to about 0.2s all future times.
 *
 * Version 0.1.11-AF - Improved algorithm for calculating button size from key spacing rather than key spacing from button size
 *                   - Added espressif32 version requirement to the platform_packages callout (not needed on some platforms, but
 *                     this should make it more compatible across development platforms)
 *                   - Changed the WiFi connect code to show the SSID and Password that is being used to connect. The password display
 *                     is dependent on defining WIFI_PASSWORD_DISPLAY, and is disabled by default
 * Version 0.1.10-AF - Support for both WT32-SC01 and generic H/W configurations. Some sample configurations are provided.
 *                   - Don't draw inactive buttons. Inactive means the logo is blank.bmp and there are no actions defined.
 *
 * Version 0.1.9-AF  - Fix to variables in wificonfig.json. Defined TOUCH_CS to avoid warning.
 *
 * Version 0.1.8-AF  - Added support for FT6236 capacitive touch screen libraryOSO
 *
 * Version 0.1.7-AF  - Fix menu1.json for brightness down button code
 *
 * Version 0.1.6-AF  - A.Fernie 2022-09-09
 *    Updates to codes sent on com port for each button press
 *
 * Version 0.1.5-AF  - A.Fernie 2022-08-27
 *    Added USB Comms functionality (like FreeTeamsDeck)
 *
 * Version 0.1.4-AF  - A.Fernie 2022-08-19
 *    Added ability to locally save general config. Allows
 *    SleepEnable status to be preserved without going through web page. Later on allow
 *    additional params like sleeptimer, colors, etc.
 *
 * Version 0.1.3-AF  - A.Fernie 2022-08-08
 *  Added monitoring of the voltage of an external battery
 *
 * Version 0.1.2-AF  - A.Fernie 2022-08-04
 * 1. Load config.json file (wasn't being read, so always used defaults)
 * 2. Fix logic for button background color so that it is based on the action for that button being
 *    a menu change or not
 * 3. Fix VSCode.bmp background color (was not completely back)
 * 4. Added some "[INFO]" messages for colors and sleepenable/sleeptimer. Note that yuou need to enable
 *    [INFO] messages by setting "#define LOG_MSG_LEVEL 3  // 1=ERROR, 2=ERROR+WARN, 3=ERROR+WARN+INFO"
 *    in CADDeck.h to see them
 * 5. No colons after [INFO], [WARN], [ERROR]
 *
 *
 * Version 0.1.1-AF  - A.Fernie 2022-07-18
 * 1. Store sample 3x5 menus
 * 2. Switch to 3x4 (more readable).
 *
 * Version 0.1.0-AF  - A.Fernie 2022-7-15
 *
 * Started from 0.9.16 and added/modified:
 * 1. Now iterates through arrays of buttons rather than using repeated code for each button in
 *    most cases. Still two sections in index.htm that use repeated code.
 * 2. Support up to a 3x5 array of buttons (limited by index.htm)
 * 3. Home page is no longer a special page that just links to five other pages, and the other pages
 *    are no longer simply five action buttons plus a link back to the home page. All buttons on
 *    each page can be actions or links. Just make sure you always have a way back.
 * 4. There are now 10 pages. This includes Menu0 (home).
 * 5. Updated to latest platformio Arduino platform (2.x)
 * 6. Changed from SPIFFS to LittleFS. Note that if you check the serial monitor output you will see
 *    some error messages like "[vfs_api.cpp:104] open(): /littlefs/list does not exist". This is a
 *    known issue with ESPAsyncWebsServer related to LittleFS supporting folders while SPIFFS does not.
 *    see https://github.com/lorol/LITTLEFS/issues/2 for more on the topic.
 * 7. Currently only working on WT32-SC01 card http://www.wireless-tag.com/portfolio/wt32-sc01/
 *
 * Version 0.9.16.
 *
 * Added UserActions. In the UserAction.h file there are a few functions you can define and
 * select through the configurator. The functions have to written before compiling. These functions
 * are then hardcoded. Look at UserActions.h for some examples.
 *
 * Added some missing characters.
 */

#ifdef USECAPTOUCH
#ifdef USE_FT6336U_LIB
#ifdef CUSTOM_TOUCH_SDA
FT6336U ts = FT6336U(PIN_SDA, PIN_SCL);
#else
FT6336U ts = FT6336U();
#endif
#else
FT6236 ts = FT6236();
#endif
#endif

AsyncWebServer webserver(80);

TFT_eSPI tft = TFT_eSPI(SCREEN_HEIGHT, SCREEN_WIDTH);  // Apparently the display is a portrait mode, but we want landscape

Preferences savedStates;

// placeholder for the pagenumber we are on (0 indicates home)
int pageNum = 0;
Stack pageHistoryStack(10);

// Initial LED brightness
int ledBrightness = 255;

// path to the directory the logo are in ! including leading AND trailing / !
char logopath[64] = "/logos/";

// templogopath is used to hold the complete path of an image. It is empty for now.
char templogopath[64] = "";

// Create instances of the structs
Menu menu[NUM_PAGES];

Wificonfig wificonfig;

Config generalconfig;
CADConfig cadconfig;
CADProgramConfig cadprogramconfig[NUM_CAD_PROGRAMS];

Generallogos generallogo;

unsigned long previousMillis = 0;
unsigned long Interval = 0;
bool displayinginfo = false;
bool displayingIOValues = false;
bool displayingButtonDescriptions = false;

char jsonFileFail[LEN_FILENAME] = "";

bool psramAvailable = false;

uint8_t last_hwbutton_state[NUM_HW_BUTTONS] = {0, 0, 0, 0, 0, 0, 0, 0, 0, 0, 0};

// Invoke the TFT_eSPI button class and create all the button objects
TFT_eSPI_Button key[BUTTON_ROWS][BUTTON_COLS];
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
void loop(void)
{
    bool pressed = false;
    uint16_t t_x = 0, t_y = 0;
    uint8_t status;

    if (millis() > (last_loop_start + loop_period)) {
        this_loop_start = millis();
        loop_count++;

        // Update and handle the joystick and physical buttons
        update_io();

        // Check and handle any commands from the serial port
        serial_commands();

        // The SpaceMouse Pro button reset
        spaceMouse.ClearButtonMask();

        // Handle the touch screen
#ifdef USECAPTOUCH
#ifdef USE_FT6336U_LIB
        FT6336U_TouchPointType touchPos;
        touchPos = ts.scan();

        if (touchPos.tp[0].tapped) {
            MSG_TOUCH_DEBUG(" Tap Detected: ");
            MSG_TOUCH_DEBUGLN(touchPos.touch_count);
            MSG_TOUCH_DEBUG(" pageNum: ");
            MSG_TOUCH_DEBUGLN(pageNum);
            MSG_TOUCH_DEBUG(" x,y: ");
            MSG_TOUCH_DEBUG(touchPos.tp[0].x);
            MSG_TOUCH_DEBUG(" : ");
            MSG_TOUCH_DEBUGLN(touchPos.tp[0].y);

            // Flip things around so it matches our screen rotation
            //         p.x = map(p.x, 0, 320, 320, 0);

            t_x = touchPos.tp[0].y;
            t_y = 320 - touchPos.tp[0].x;
            pressed = true;
        }
        else {
            pressed = false;
        }
#else
        if (ts.touched()) {
            // Retrieve a point
            TS_Point p = ts.getPoint();

            // Flip things around so it matches our screen rotation
            p.x = map(p.x, 0, 320, 320, 0);
            t_y = p.x;
            t_x = p.y;

            pressed = true;
        }
        else {
            pressed = false;
        }
#endif
#else
        pressed = tft.getTouch(&t_x, &t_y);
#endif

        if (pageNum == WEB_REQUEST_PAGE) {
            // If the pageNum is set to NUM_PAGES+1, do not draw anything on screen or check for touch
            // and start handling incomming web requests.
        }
        else if (pageNum == SPECIAL_PAGE_INFO) {
            if (!displayinginfo) {
                printinfo();
            }

            if (pressed) {
                displayinginfo = false;

                pageNum = pageHistoryStack.pop(&status);
                if(!isValidPageNumber(pageNum)){
                    MSG_ERROR1("[ERROR] Invalid page number: ", pageNum);
                    pageNum = 0;
                }
                else if (status == STACK_STATUS_EMPTY) {
                    MSG_ERRORLN("[ERROR] Page History Stack is empty. Cannot pop page so switching to home page.");
                    pageNum = 0;
                }

                tft.fillScreen(generalconfig.backgroundColour);
                drawKeypad();
            }
        }
        else if (pageNum == SPECIAL_PAGE_IO_MONITOR) {
            printIOValues();

            if (pressed) {
                displayingIOValues = false;
                pageNum = pageHistoryStack.pop(&status);

                if (!isValidPageNumber(pageNum)) {
                    MSG_ERROR1("[ERROR] Invalid page number: ", pageNum);
                    pageNum = 0;
                }
                else if (status == STACK_STATUS_EMPTY) {
                    MSG_ERRORLN("[ERROR] Page History Stack is empty. Cannot pop page so switching to home page.");
                    pageNum = 0;
                }

                tft.fillScreen(generalconfig.backgroundColour);
                drawKeypad();
            }
        }
        else if (pageNum == SPECIAL_PAGE_BUTTON_INFO) {
            if (!displayingButtonDescriptions) {
                printButtonInfo(cadconfig.current_program);
            }

            if (pressed) {
                displayingButtonDescriptions = false;

                pageNum = pageHistoryStack.pop(&status);
                if (!isValidPageNumber(pageNum)) {
                    MSG_ERROR1("[ERROR] Invalid page number: ", pageNum);
                    pageNum = 0;
                }
                else if (status == STACK_STATUS_EMPTY) {
                    MSG_ERRORLN("[ERROR] Page History Stack is empty. Cannot pop page so switching to home page.");
                    pageNum = 0;
                }

                tft.fillScreen(generalconfig.backgroundColour);
                drawKeypad();
            }
        }
        else if (pageNum == SPECIAL_3_PAGE) {
            // We were unable to connect to WiFi. Waiting for touch to get back to the settings menu.

            if (pressed) {
                // Return to Settings page
                displayinginfo = false;

                pageNum = pageHistoryStack.pop(&status);
                if (!isValidPageNumber(pageNum)) {
                    MSG_ERROR1("[ERROR] Invalid page number: ", pageNum);
                    pageNum = 0;
                }
                else if (status == STACK_STATUS_EMPTY) {
                    MSG_ERRORLN("[ERROR] Page History Stack is empty. Cannot pop page so switching to home page.");
                    pageNum = 0;
                }

                tft.fillScreen(generalconfig.backgroundColour);
                drawKeypad();
            }
        }
        else if (pageNum == SPECIAL_4_PAGE) {
            // A JSON file failed to load. We are drawing an error message. And waiting for a touch.

            if (pressed) {
                // Load home screen
                displayinginfo = false;

                pageNum = pageHistoryStack.pop(&status);
                if (!isValidPageNumber(pageNum)) {
                    MSG_ERROR1("[ERROR] Invalid page number: ", pageNum);
                    pageNum = 0;
                }
                else if (status == STACK_STATUS_EMPTY) {
                    MSG_ERRORLN("[ERROR] Page History Stack is empty. Cannot pop page so switching to home page.");
                    pageNum = 0;
                }
                tft.fillScreen(generalconfig.backgroundColour);
                drawKeypad();
            }
        }
        else {
            // Check if sleep is enabled and if our timer has ended.

#ifdef TOUCH_INTERRUPT_PIN
            if (generalconfig.sleepenable) {
                if (millis() > previousMillis + Interval) {
                    // The timer has ended and we are going to sleep  .
                    tft.fillScreen(TFT_BLACK);
                    MSG_INFOLN("[INFO] Going to sleep.");
#ifdef speakerPin
                    if (generalconfig.beep) {
                        ledcAttachPin(speakerPin, 2);
                        ledcWriteTone(2, 1200);
                        delay(150);
                        ledcDetachPin(speakerPin);
                        ledcWrite(2, 0);

                        ledcAttachPin(speakerPin, 2);
                        ledcWriteTone(2, 800);
                        delay(150);
                        ledcDetachPin(speakerPin);
                        ledcWrite(2, 0);

                        ledcAttachPin(speakerPin, 2);
                        ledcWriteTone(2, 600);
                        delay(150);
                        ledcDetachPin(speakerPin);
                        ledcWrite(2, 0);
                    }
#endif
                    MSG_INFOLN("[INFO] Saving latched states");

                    esp_sleep_enable_ext0_wakeup(TOUCH_INTERRUPT_PIN, 0);
                    esp_deep_sleep_start();
                }
            }
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

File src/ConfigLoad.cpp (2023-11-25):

#include "ConfigLoad.h"
/**
 * @brief This function opens wificonfig.json and fills the wificonfig
 *        struct accordingly.
 *
 * @param none
 *
 * @return True when succeeded. False otherwise.
 *
 * @note This is also where the sleep configuration lives.
 */
bool loadMainConfig()
{
    MSG_INFOLN("[INFO] Entering loadMainConfig");
    if (!FILESYSTEM.exists("/config/wificonfig.json")) {
        MSG_WARNLN("[WARNING]: Config file not found!");
        return false;
    }
    File configfile = FILESYSTEM.open("/config/wificonfig.json");

    DynamicJsonDocument doc(384);

    DeserializationError error = deserializeJson(doc, configfile);

    if (error == DeserializationError::Ok) {
        MSG_INFOLN("[INFO] wificonfig.json deserialized loaded OK");
    }
    else {
        MSG_WARN1("[WARNING]: wificonfig.json deserialization error: ", error.c_str());
    }

    strlcpy(wificonfig.ssid, doc["ssid"] | "FAILED", sizeof(wificonfig.ssid));
    strlcpy(wificonfig.password, doc["password"] | "FAILED", sizeof(wificonfig.password));
    strlcpy(wificonfig.wifimode, doc["wifimode"] | "FAILED", sizeof(wificonfig.wifimode));
    strlcpy(wificonfig.hostname, doc["wifihostname"] | "CADDeck", sizeof(wificonfig.hostname));

    uint8_t attempts = doc["attempts"] | 10;
    wificonfig.attempts = attempts;

    uint16_t attemptdelay = doc["attemptdelay"] | 500;
    wificonfig.attemptdelay = attemptdelay;

    configfile.close();

    if (error) {
        MSG_ERROR("[ERROR] deserializeJson() error");
        MSG_ERRORLN(error.c_str());
        return false;
    }

    return true;
}

/**
* @brief This function loads the menu configuration.
*
* @param String the config to be loaded
*
* @return none
*
* @note Options for values are: colors, menu1, menu2, menu3
         menu4, and menu5
*/
bool loadConfig(String value)
{
    char fileNameType[LEN_FILENAME];
    int fileNameMenuNumber = 0;
    int numConverted = 0;
    numConverted = sscanf(value.c_str(), "%4s%d", fileNameType, &fileNameMenuNumber);
    MSG_INFO2("[INFO] load_config parameter", value.c_str(), numConverted);

    if (value == "general") {
        File configfile = FILESYSTEM.open("/config/general.json", "r");

        DynamicJsonDocument doc(512);

        DeserializationError error = deserializeJson(doc, configfile);

        // Parsing colors
        const char *menubuttoncolor = doc["menubuttoncolor"] | "#009bf4";          // Get the colour for the menu and back home buttons.
        const char *functionbuttoncolor = doc["functionbuttoncolor"] | "#00efcb";  // Get the colour for the function buttons.
        const char *latchcolor = doc["latchcolor"] | "#fe0149";                    // Get the colour to use when latching.
        const char *bgcolor = doc["background"] | "#000000";                       // Get the colour for the background.

        char menubuttoncolorchar[64];
        strcpy(menubuttoncolorchar, menubuttoncolor);
        unsigned long rgb888menubuttoncolor = convertHTMLtoRGB888(menubuttoncolorchar);
        generalconfig.menuButtonColour = convertRGB888ToRGB565(rgb888menubuttoncolor);

        char colorbuf[64];
        snprintf(colorbuf, sizeof(colorbuf), "[INFO] menuButtonColour (RGB565) = 0x%06X", generalconfig.menuButtonColour);
        MSG_INFOLN(colorbuf);

        char functionbuttoncolorchar[64];
        strcpy(functionbuttoncolorchar, functionbuttoncolor);
        unsigned long rgb888functionbuttoncolor = convertHTMLtoRGB888(functionbuttoncolorchar);
        generalconfig.functionButtonColour = convertRGB888ToRGB565(rgb888functionbuttoncolor);

        snprintf(colorbuf, sizeof(colorbuf), "[INFO] functionButtonColour (RGB565) = 0x%06X", generalconfig.functionButtonColour);
        MSG_INFOLN(colorbuf);

        char latchcolorchar[64];
        strcpy(latchcolorchar, latchcolor);
        unsigned long rgb888latchcolor = convertHTMLtoRGB888(latchcolorchar);
        generalconfig.latchedColour = convertRGB888ToRGB565(rgb888latchcolor);

        snprintf(colorbuf, sizeof(colorbuf), "[INFO] latchedColour (RGB565) = 0x%06X", generalconfig.latchedColour);
        MSG_INFOLN(colorbuf);

        char backgroundcolorchar[64];
        strcpy(backgroundcolorchar, bgcolor);
        unsigned long rgb888backgroundcolor = convertHTMLtoRGB888(backgroundcolorchar);
        generalconfig.backgroundColour = convertRGB888ToRGB565(rgb888backgroundcolor);

        snprintf(colorbuf, sizeof(colorbuf), "[INFO] backgroundColour (RGB565) = 0x%06X", generalconfig.backgroundColour);
        MSG_INFOLN(colorbuf);

        // Loading general settings

        bool sleepenable = doc["sleepenable"] | false;
        if (sleepenable) {
            generalconfig.sleepenable = true;
        }
        else {
            generalconfig.sleepenable = false;
        }

        uint16_t sleeptimer = doc["sleeptimer"] | 60;
        generalconfig.sleeptimer = sleeptimer;
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

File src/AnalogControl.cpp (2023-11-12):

/*
  AnalogControl.cpp

  Copyright (c) 2022, Andrew Fernie

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
  You should have received a copy of the GNU Lesser General Public
  License along with this library; if not, write to the Free Software
  Foundation, Inc., 51 Franklin St, Fifth Floor, Boston, MA  02110-1301  USA
*/

#include "AnalogControl.h"

AnalogControl::AnalogControl(
    uint8_t pin_a)
{
    gpio_pin_a = pin_a;
    zero_a = 0;
    value_int_a = 0;
    scale_a = 1.0;
    deadzone = 0.0;
}

AnalogControl::~AnalogControl()
{
}

/**
 * Initializes the analog control by setting the pin mode to INPUT and calibrate its zero point.
 */
void AnalogControl::Init()
{
    pinMode(gpio_pin_a, INPUT);
    CalibrateZero();
}

void AnalogControl::SetDeadzone(float dz)
{
    deadzone = dz;
};

float AnalogControl::GetDeadzone()
{
    return deadzone;
};

void AnalogControl::SetScale(float scale)
{
    scale_a = scale;
};

float AnalogControl::GetScale()
{
    return scale_a;
};

uint8_t AnalogControl::Update()
{
    // make sure the pin is valid
    if (gpio_pin_a == 0) {
        return 1;
    }

    // read the AnalogControl
    value_int_a = analogRead(gpio_pin_a);
    return 0;
}

uint8_t AnalogControl::CalibrateZero()
{
    // make sure the pin is valid
    if (gpio_pin_a == 0) {
        return 1;
    }

    // calibrate the AnalogControl mid point
    int in_a = 0;
    for (int i = 0; i < 100; i++) {
        Update();
        in_a += value_int_a;
        delay(10);
    }

    zero_a = in_a / 100;
    value_int_a = zero_a;

    return 0;
}

uint8_t AnalogControl::CalibrateScale()
{
    // make sure the pins are valid
    if (gpio_pin_a == 0) {
        return 1;
    }

    // calibrate the AnalogControl scale
    int max_value_a = -10000;
    int min_value_a = 10000;

    long timestart = millis();

    while (millis() - timestart < 5000) {
        Update();
        if (value_int_a > max_value_a) {
            max_value_a = value_int_a;
        }
        else if (value_int_a < min_value_a) {
            min_value_a = value_int_a;
        }
    }
    scale_a = 2.0 / (float)(max_value_a - min_value_a) * 4095.0;
    return 0;
}

/**
 * Returns the current value of the analog control.
 * @return The current value of the analog control.
 */
float AnalogControl::Value()
{
    float value = (value_int_a - zero_a) * scale_a / 4095.0;
    if (value > deadzone) {
        value = min(max((float)0.0, value - deadzone), (float)1.0);
    }
    else if (value < -deadzone) {
        value = max((float)-1.0, min((float)0.0, value + deadzone));
    }
    else {
        value = 0.0;
    }
    return value;
};

int AnalogControl::RawValue()
{
    return value_int_a;
};

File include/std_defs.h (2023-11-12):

#pragma once
#include <stdint.h>
const uint8_t ReturnSuccess = 0;
const uint8_t ReturnFail = 1;

#ifdef LOG_MSG_PORT
#define MSG_PORT LOG_MSG_PORT
#else
#define MSG_PORT Serial
#endif

#ifndef LOG_MSG_BASIC
//#define LOG_MSG_BASIC 0       // off
#define LOG_MSG_BASIC 1         // on
#endif

#ifndef LOG_MSG_LEVEL
//#define LOG_MSG_LEVEL 0         // off
#define LOG_MSG_LEVEL 1         // ERROR
//#define LOG_MSG_LEVEL 2         // ERROR, WARN
//#define LOG_MSG_LEVEL 3         // ERROR, WARN, INFO
#endif

#ifndef LOG_MSG_DEBUG
#define LOG_MSG_DEBUG 0  // off
//#define LOG_MSG_DEBUG 1         // on
#endif

#ifndef LOG_MSG_TOUCH_DEBUG
#define LOG_MSG_TOUCH_DEBUG 0  // off
//#define LOG_MSG_TOUCH_DEBUG 1         // on
#endif
#ifndef USE_DEBUG_PINS
#define USE_DEBUG_PINS 0  // off
#endif
#define INIT_DEBUG_PIN(x) \
    if (USE_DEBUG_PINS > 0) { \
        pinMode(x, OUTPUT);   \
    }
#define WRITE_DEBUG_PIN(x, y) \
    if (USE_DEBUG_PINS > 0) { \
        digitalWrite(x, y);   \
    }

#define MSG_BASICLN(x)       \
    if (LOG_MSG_BASIC) {     \
        MSG_PORT.println(x); \
    }
#define MSG_BASIC(x)       \
    if (LOG_MSG_BASIC) {   \
        MSG_PORT.print(x); \
    }
#define MSG_BASIC1(x, y)     \
    if (LOG_MSG_BASIC) {     \
        MSG_PORT.print(x);   \
        MSG_PORT.print(" "); \
        MSG_PORT.println(y); \
    }
#define MSG_BASIC1F(x, y)       \
    if (LOG_MSG_BASIC) {        \
        MSG_PORT.printf(x, y);  \
    }
#define MSG_BASIC2(x, y, z)  \
    if (LOG_MSG_BASIC) {     \
        MSG_PORT.print(x);   \
        MSG_PORT.print(" "); \
        MSG_PORT.print(y);   \
        MSG_PORT.print(" "); \
        MSG_PORT.println(z); \
    }
#define MSG_BASIC3(x, y, z, w) \
    if (LOG_MSG_BASIC) {       \
        MSG_PORT.print(x);     \
        MSG_PORT.print(" ");   \
        MSG_PORT.print(y);     \
        MSG_PORT.print(" ");   \
        MSG_PORT.print(z);     \
        MSG_PORT.print(" ");   \
        MSG_PORT.println(w);   \
    }

#define MSG_ERRORLN(x)       \
    if (LOG_MSG_LEVEL > 0) { \
        MSG_PORT.println(x); \
    }
#define MSG_ERROR(x)         \
    if (LOG_MSG_LEVEL > 0) { \
        MSG_PORT.print(x);   \
    }
#define MSG_ERROR1(x, y)     \
    if (LOG_MSG_LEVEL > 0) { \
        MSG_PORT.print(x);   \
        MSG_PORT.print(" "); \
        MSG_PORT.println(y); \
    }
#define MSG_ERROR1F(x, y)      \
    if (LOG_MSG_LEVEL > 0) {   \
        MSG_PORT.printf(x, y); \
    }
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

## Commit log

2023-02-19 More info in the README Cleanup some of the images Assign Button 4 (visibility "v" for Fusion360), (hide "TAB" for Solidworks)
2023-04-19 First try for 10 button version with analog control rather than encoder for zoom
2023-04-23 1. Add 10th button to cadparams.json for all CAD programs. 2. Disable most console messages to see if that improves wifi functionality. 3. Define second set of button pins to allow switching between 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
2023-04-29 Work on 10 button version: 1. Make it 10 buttons rather than 9 (0 based index issue) 2. Fix save/load of axis pan/til/zoom/rotate 3. Show selected H/W button number 4. Don't limit axis scaling values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
    [Action.cpp, CADDeck.h, ConfigLoad.cpp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]
2023-05-08 Zoom active without pressing button.
2023-05-13 Updates to joystick control logic so that if the button is not pressed the joystick controls pan and tilt. Keys and mouse button states are always cleared if no control is away from zero.
2023-05-13 Denoise comparisons of controls being centered before switching to mouse mode.
2023-05-14 Initialize active cad program in configurator. Default behavior of 10 buttons for Fusion 360 is to send letters a-j (setup debug aid).
2023-05-29 Some advance work to allow switch between Bluetooth and USB. Allow upload of cadparams.json
2023-06-11 Add controllable GPIO pin functions for LED control.
2023-06-24 Enum for mouse button and option key actions
    Added enum for mouse button and option key actions and used those enum in Physical_IO.cpp to make the code easier to understand.
2023-10-15 Correct pin for LED cotrol and initialize to 1 (on)
2023-10-15 Use proper pin definition for mode switch.
2023-10-20 Changes to F360m button definitions from AFUDirk
2023-10-20 Button pin definition from AFUDirk
2023-10-20 Reworked control logic. 1. If mode button (button 0) is not selected a. push/pull knob = rotate pitch b. twist knob = rotate yaw c. joystick move X, Y = mouse move X,Y 2. If mode button (button 0) is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
2023-10-22 Add handlers for single and double "clicks" of mode button. A click is typically used to select whatever is under the mouse pointer.
2023-10-29 Added description field for H/W buttons.
2023-11-09 More SpaceMouse
    Bug fix for SpaceMouse button numbering
    Start on support for all 15 buttons on SpaceMouse Pro (Work In Progress)
    Image to show mapping between CADDeck and SpaceMouse button numbers
    [Action.cpp, CADDeck.cpp, CADDeck.h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]
2023-11-12 Initial release emulating a SpaceMouse Pro
    Initial release with functional interface with 3dconnexion drivers emulating a SpaceMouse Pro. Needs this code https://github.com/andrewfernie/magellan-spacemouse loaded on a Raspberry Pi Pico to pro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
    [SpaceMouse Pro Button Mapping .xlsx]
2023-11-12 Enable knob push/pull (vertical move) while in rotation mode and knob rotate when in translation mode
    Add SpaceMouse soft button support to configurator
2023-11-13 Merge 10_button version code into main.
    Merge 10_button version code into main, create new branch "Version_1..." for the original version (now deprecated), and reference AFUDirk's github for the currently supported hardware.
2023-11-17 Fixes for: 1. Missing commas in "handleinfo" JSON formatted string 2. Error in spelling of spacemouse_enable 3. Update to V1.1.2 4. Eliminate duplicate id='save' in index.htm
    [CADDeck.cpp, CADDeck.h, SaveConfig.cpp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]
2023-11-25 Fix issues with H/W button description handling (wasn't saving, and possible buffer overflows) Prevent possible buffer overflow in filenames (mainly logos)
    [Action.cpp, CADDeck.cpp, CADDeck.h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]
2023-11-26 - Started work on support for multiple H/W buttons held down at the same time - Renamed BLE device to "CADDeck"
2023-11-26 Fix bug in start of simultaneous button presses that was stopping all SpaceMouse functionality. Added an svg file (from Inkscape) with a key label pattern.
    [CADDeck.cpp]
2023-11-29 - Started work on support for multiple H/W buttons held down at the same time - Renamed BLE device to "CADDeck" - Fixed issues with "return to previous page" stack when not on page 0 at start - Added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
    [Action.cpp, CADDeck.cpp, CADDeck.h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]
2023-12-03 Configure 3dx Solidworks Aseembly button setup
